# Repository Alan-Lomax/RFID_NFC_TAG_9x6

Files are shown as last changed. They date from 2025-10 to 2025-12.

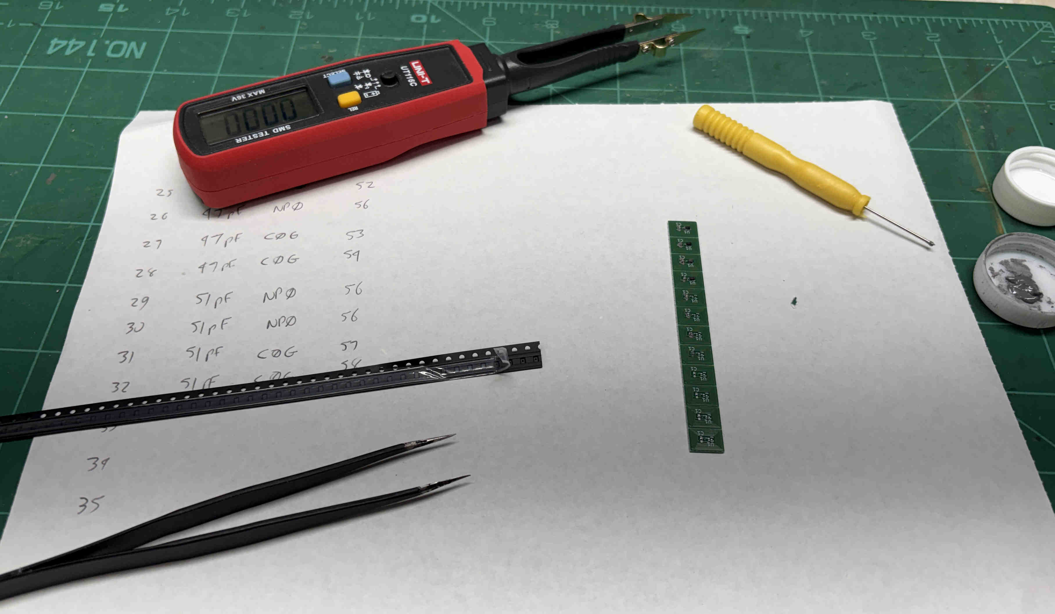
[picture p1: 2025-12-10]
Photos and testing/91 New Strip with varying C values.jpg

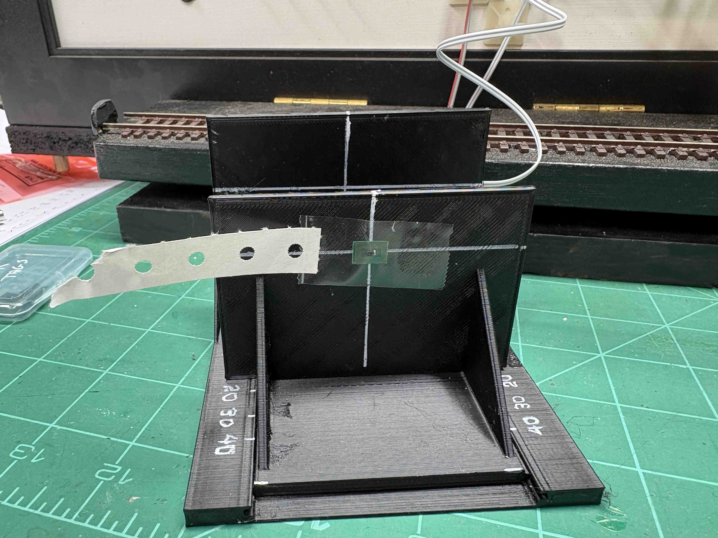
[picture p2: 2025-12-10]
Photos and testing/92 3D printed jig for range testing.jpg

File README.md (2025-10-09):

# RFID TAGs (PCB's and supporting documents)

## RFID_NFC_TAG_9x6
A simple small 9x6 mm PCB which uses two additional components to make up an RFID tag.
These are intended for use on model railways but applicable to other things.

## Description
Schematic KiCad files are included along with the GERBER files ready to send to a fab house for building.
It is recommended to have these panelized by the fab house into an array.
e.g.: 10 x 10 array for 100 tags per PCB). With the typical minimum order of 5 PCBs this will get you 500 tags.
Note that if the fab house can get the parts these PCB's could be ordered 'built' (With an associated cost of course)

For home assembly some experience with surface mount component assembly is recommended (hot plate method). 

## Technical
Designed for 13.56 MHz using the ISO15693 (vicinity Card) standard.
    Uses an NXP SL2S2602FTBX three pin IC (very small)
    And a 43pF capacitor for antanna matching ( 0402 SMD = very small )

## Other Equipment
For a complete RFID solution a tag also needs a suitable reader in order to energize the tag and get the information from it. 
For testing purposes I am using the StaRFIshRail hardware designed by the late Martin Snashell (no longer available)

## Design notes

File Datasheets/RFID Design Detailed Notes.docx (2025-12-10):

MERG RFID

General Architecture

Block Diagram Status | Data Concentrator RFID Reader Aerial Tag
| Data Concentrator | RFID Reader | Aerial | TAG
IFC | Purpose: Receive data from one or more readers and redistribute it in a commonly understood and well-defined format for use by established data consumers like JMRI | Purpose: Provide RF power and messaging to one or more aerials according to a well-defined industry standard protocol. Forward the received messages to the data concentrator along with an identifier as to what aerial was involved. | Purpose: Radiate the RFID energy in a detection field large enough for the model railway application but without excessive range that would result in spurious signals. | Purpose: Receive the RF energy power up and respond back to reader via the aerial (when in range) with at minimum the manufacturer assigned GUID. Do this fast enough for reliable reads as the tag passes over the aerial at a scale locomotive speed in excess of 100 MPH.
IFC | Left Side (IN) configuration data for MQTT HUB, CBUS address, events. Left Side (Out) MQTT+JSON and / or CBUS payloads Right Side: I2C messages to and from RFID Reader | Left Side (IN) I2C messages from Data Concentrator Left Side Out: I2C Payload data {Aerial #, GUID} Right Side: ISO/IEC 15693 RF messaging | In / Out: ISO/IEC 15693 RF messaging | In / Out: ISO/IEC 15693 RF messaging
IFC | TBD (Ras Pi PICO for example) | TBD (custom MERG board) | MOLEX 25mm x 15mm | Custom small PCB SL2S2602FTBX IC (https://www.nxp.com/products/SL2S2602) MLCC for Tuning
IFC | Investigating | Investigating | Lead lengths need to be matched with reader passives | Prototype designed and ordered. Parts on hand.

IFC = Issued for Comment

Designing My RFID Tag

As the design evolves regarding dimensions, number of turns, chip selection, then so dies the need for and value of a matching capacitor. Starting with the chip selection I wanted a currently Active product (not an obsolete or soon to be obsolete one). Using Application note AN11809 (https://www.nxp.com/docs/en/application-note/AN11809.pdf) (A product Comparison) I quickly settled on the SLIX 2 family and specifically the SL2S2602 family. (Must use that number to search for a data sheet, do not include the packaging suffix). A specific packaging of the chip is the SL2S2602FTBX which is the desired 3 pin SMD version.

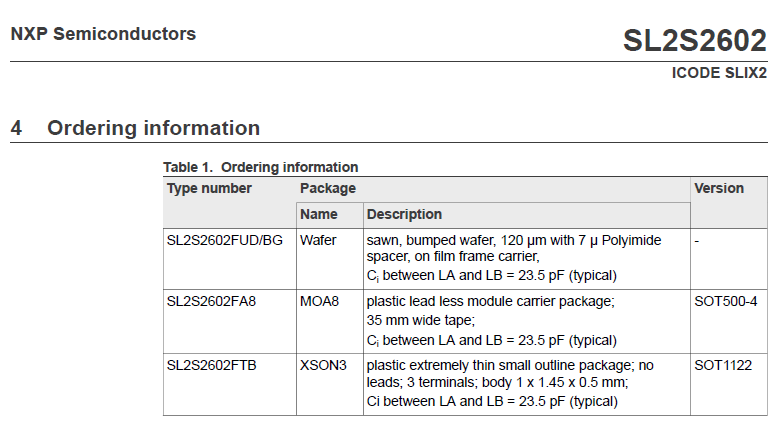
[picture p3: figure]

From the NXP website using the antenna calculator (link here (https://community.nxp.com/t5/NFC/bd-p/nfc?profile.language=en)) a matching capacitor of 42.2 pF is needed (nearest standard value is 43pF)

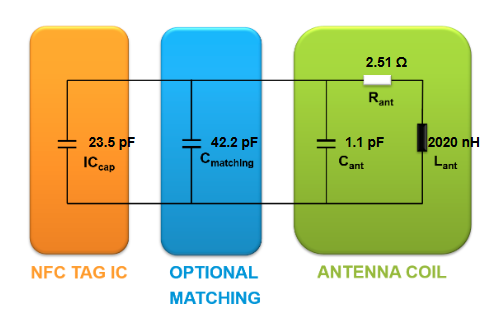
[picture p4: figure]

My specific design is below (created in KiCad Sept 15 2025). The tag below is 9mm x 6.5 mm on a 1mm thick FR4 PCB. There are 9 turns on each side (18 turns in total). The selected capacitor is in 0402 form (very small) and the chip is similarly tiny being in a XSON3 form factor. (see here (https://www.nxp.com/packages/SOT1122))

Both are of course surface mount.

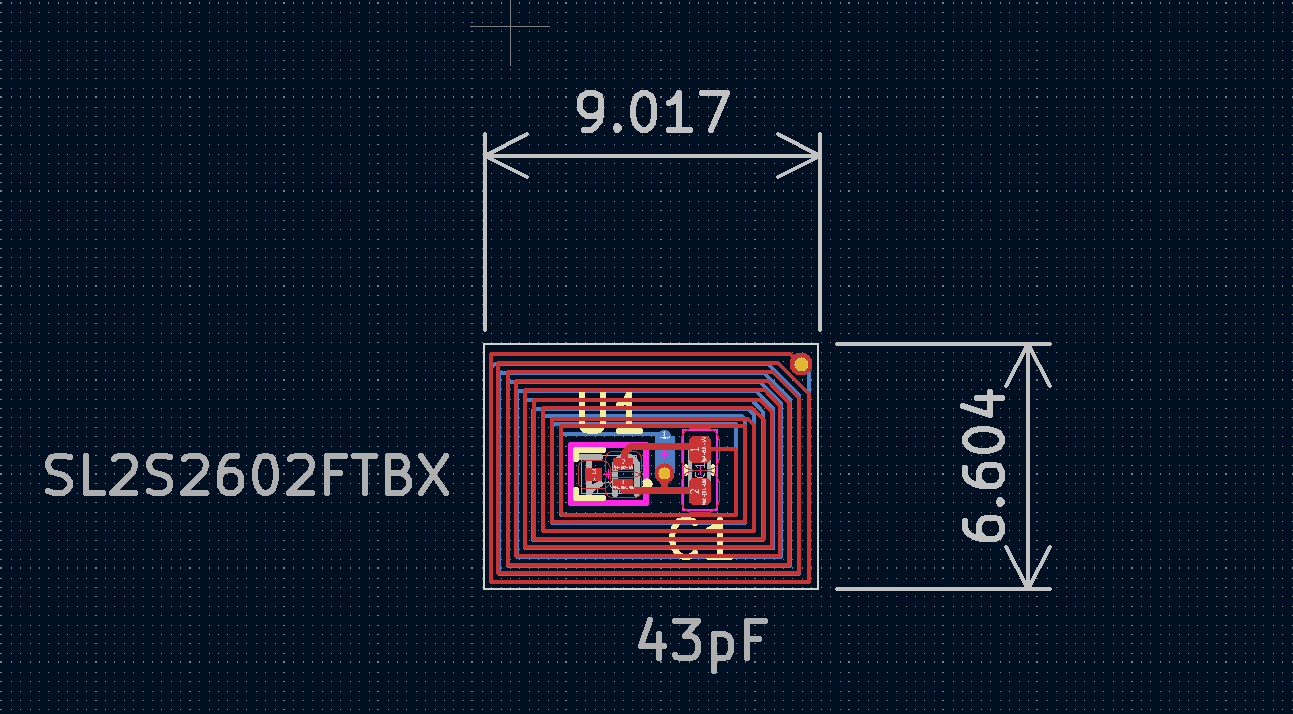
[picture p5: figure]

Above is the original PCB. Has since been tidied up a bit with slightly larger pads for NXP IC and more uniform aerial spacing. The Rev b has not been ordered (yet)

Purchase Details

Order number: Y46-4884191A

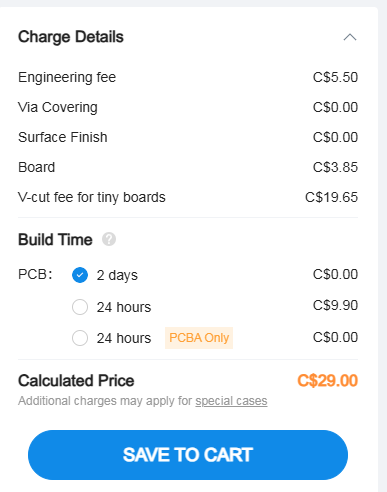
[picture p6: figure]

Note much higher V cut fee for tiny boards. In this case I am getting a 10 x 12 array.

(Limit for V-Cuts is 25 in each direction – so not close in that regard.)

Next is to source the components:

After Google Search … Mouser Canada.

## Order Number: 36928084 (https://www.mouser.ca/account/orders/detail)

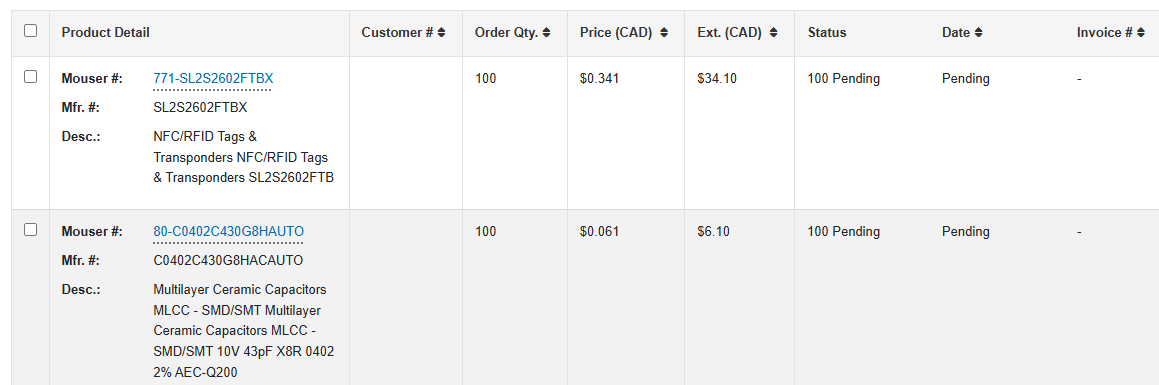
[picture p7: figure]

100 each of NXP chip and 0402 43pF Capacitor ($67 including $20 shipping) all in Canadian dollars.

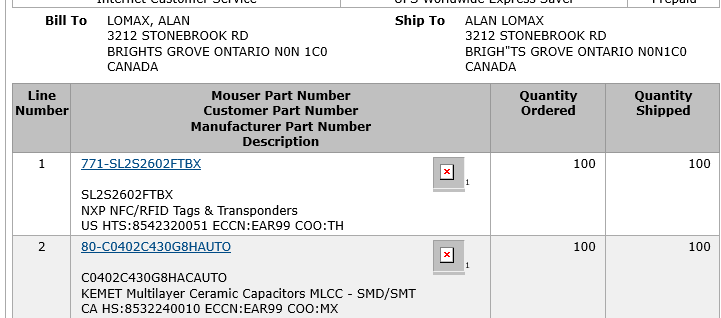
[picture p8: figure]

Mouser picked the parts and shipped them the same day.

On UNIT COST

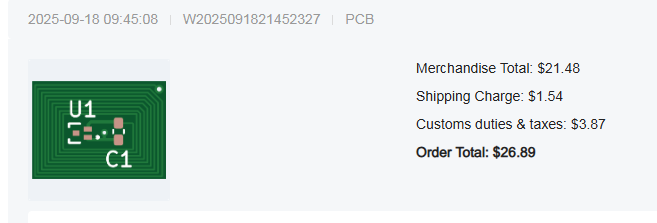
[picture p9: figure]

The PCB’s were about $30. Quite a bit higher than normal because there was a higher surcharge for “VeeCuts on Tiny boards”. Note – this is for Qty 5 PCBs that are 100mm x 100 mm. Each PCB has a 10x12 array of tags … so 600 tags for $30 works out to 5 cents for each Tag. The chips and capacitors were $68 Canadian for 100 of each (and $20 of that was for shipping.) so that is about $0.68 for those pieces. Per tag all in cost is 73 cents.

Pre-Assembled aka ‘Stuffed’ boards

It would be ideal to know what the ‘assembled cost’ would be from the likes of JLCPCB as for the tags specifically I think that would be preferred.

The process is described below:

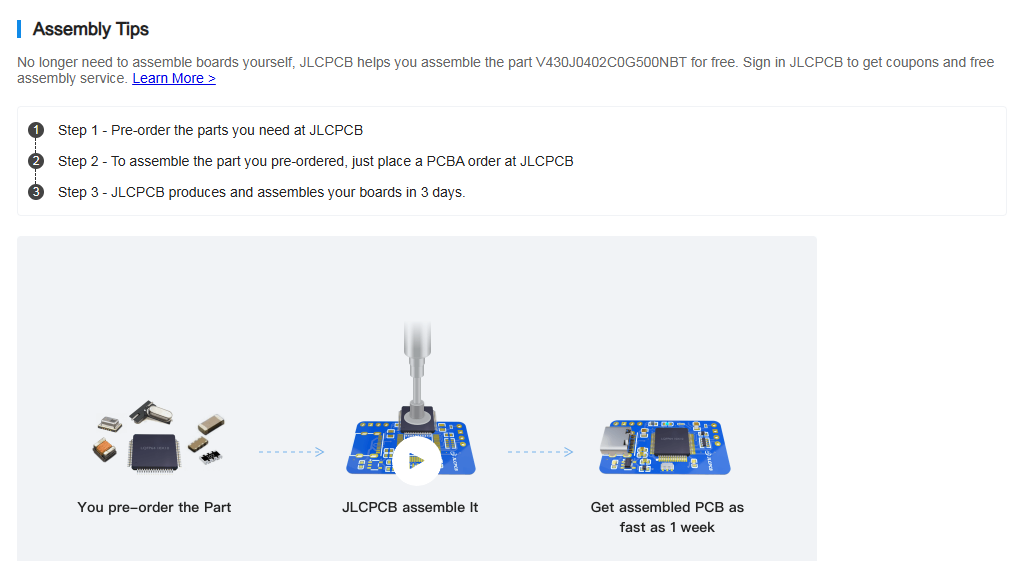
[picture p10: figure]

Investigating further: JLCPCB has in stock the capacitors (26k of them) and the NXP IC’s (Only 5 of them).

Preordering the IC’s triggered a minimum order size (but it was small at about 30 pieces) In qty 100 the ICs were about 55 cents each, the capacitors were under a penny each. What was not known is the engineering fee that might apply.

Commercial NXP Tags

(not explored yet)

Useful Network Analysis (Educational)

VSWR explained: https://www.youtube.com/watch?v=BijMGKbT0Wk

S parameters: https://www.youtube.com/watch?v=-Pi0UbErHTY

Smith Chart explained https://www.youtube.com/watch?v=rUDMo7hwihs

Common English “S term” translations

S21 – gain (Out is port 2, and in is Port 1)

S12 – noise blocking (Signal coming out of Port 1, from the port 2 side)

S11 – signal reflection (Power in on port 1 is also coming out on port 1)

S22 – signal reflection (ditto Port 2)

Build up and Testing of First Batch

Sep 30 2025

Prep

Solder paste was chosen with an indicated melt of 183 Deg C

A small dab was placed in the lid and mixed with a drop of IPA to make it smooth and creamy (was slightly grainy)

Used a solder aid tool to transfer miniscule dabs onto the solder pads.

For capacitor this was quite practical (larger pads).

For RFID chip the triad of pins were small and too close together and typically one blob covered all three.

With very fine tweezers parts were picked and verified for orientation (third pin is a tell tale) before placing on the paste.

Parts were only removed from packaging 4 at a time and only once placed were 4 more taken out of tape reel package.

The hot plate for pre heated to a pre soak temperature of 100 Deg C

Bake

The PCB with two complete rows was carefully put on the hot plate for a pre soak at 100 Deg C (5 minutes)

The temp was raised in stages with a short hold period at each (First hold was at 145 C, then 190 C and then finally temp was raised up to 205 C)

At 145 the IPA was obviously driven off – texture of solder paste changed.

At 190 some solder melt was occurring (but not the majority)

At 205C widespread melt was occurring in most places and this temperature was then held for 10 minutes.

It was noticed that one IC had popped up in the air 90 degrees to board. (In situ poking was attempted)

A close inspection then showed that capacitor on Tag 1 was MIA. A new one was retrieved from package and put in place
Cool Down | Hot plate was switched off and allowed to cool down. The PCB was removed from the hot plate (which was warm but not hot at this stage)
Prelim Testing | Using the StaRFIshRail test rig that I have I was able to test these tags for a simple go/no-go functionality test. Of the 24 tags only 4 failed. (Awesome result in my opinion)
Next Steps | Get my MQTT client up and running Scan the Working tags will be scanned for their UID Inspect and repair where possible the 4 failed tags.
Oct 1 2025
| Got my Raspberry Pi 4 up and running. It had a lot of updates to do. I reinstalled Eclipse mosquitto and it took a while to get it configured so that the HUB knew about the new IP address and that multiple clients were reading (subscribing) to it. Got there in the end.

# | Init P/F | Next Day GUID Read | GUID | Inspection Findings And Comments

1 | F | No response | No response | Misaligned IC. Touch with Solder Iron Retested. Failed (3x)
2 | P | | 09184854B8
3 | P | Failed to read | 09184854AA | Obvious paste. Touch C1 with Solder Iron Retested good
4 | P | | 09184854B0
5 | P | | 09184854BA
6 | P | | 09184854AD
7 | P | | 09184854B5
8 | P | | 09184854BB
9 | F | No response | No response | Misaligned IC. Touch with Solder Iron Retested. Failed (3x)
10 | P | | 09184854B1
11 | P | | 09184854BD
12 | P | | 09184854B2
13 | P | | 09184854A5
14 | P | | 09184854BC
15 | P | | 09184854AB
16 | P | | 09184854B7
17 | F | Failed to read | 09184854A9 | Misaligned Cap. Touch with Solder Iron Retested Good
18 | P | | 09184854AE
19 | P | | 09184854BE
20 | F | Failed to read | 09184854A7 | Misaligned Cap. Touch with Solder Iron Retested Good
21 | P | | 09184854B4
22 | P | | 09184854B9
23 | P | Failed to read | 09184854A2 | Nothing Obvious. Touch C1 with Solder Iron Retested good
24 | P | | 09184854AC

Below is board “as completed”

- Yellow squares indicate the initial failed positions.
- Orange squares failed the following day
- After rework only 1 and 9 remained inoperable (red dashed outline)

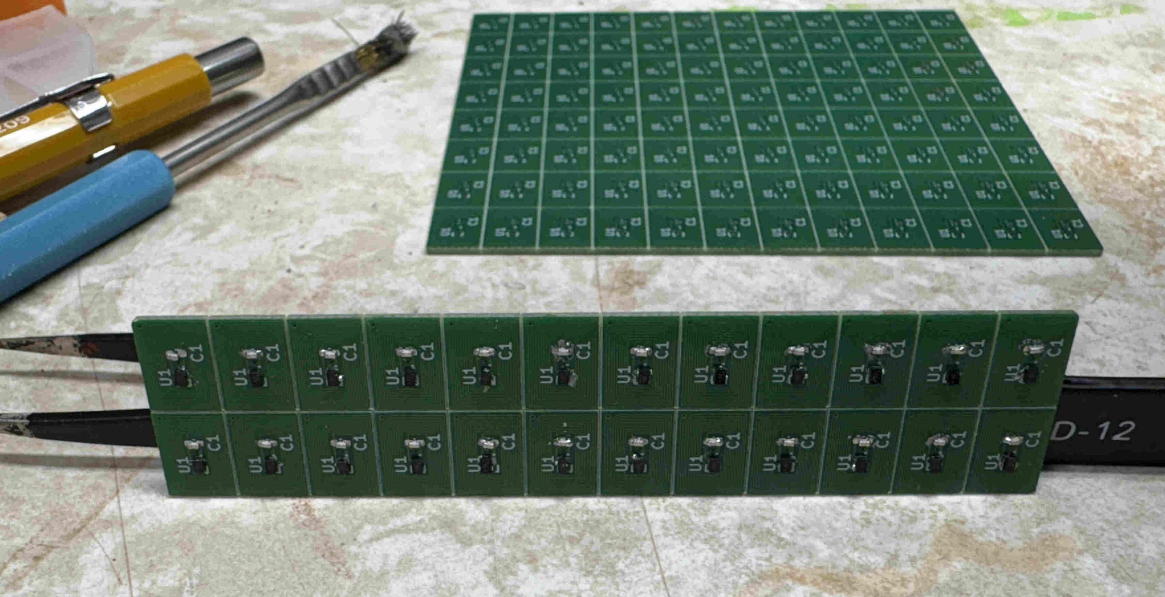
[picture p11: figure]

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
To: | David Harris 1545 York Place Victoria, BC Canada V8R 5X1
Tel | 250-216-0641
Item | Qty
PCB’s | 24
Capacitor C1 (43pF 50V MLCC) | 5
NFC RFID Chip SL2S2602FTBX | 5
Completed Boards | 5 | 6,12,14,15,24

David Harris

1545 York Place

Victoria, BC

Canada

V8R 5X1

To: | Nick Murphy 34 Droxford Crescent, Tadley, Basingstoke, Hampshire, England, RG26 3BA
Tel
Item | Qty
PCB’s | 24
Capacitor C1 (43pF 50V MLCC) | 5
NFC RFID Chip SL2S2602FTBX | 5
Completed Boards | 5 | 2,7,10,11,18

Mr. Nick Murphy

34 Droxford Crescent,

Tadley, Basingstoke,

Hampshire, England,

RG26 3BA

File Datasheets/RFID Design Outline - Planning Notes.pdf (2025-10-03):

MERG RFID

General Architecture

Block Diagram Status | Data RFID Reader Aerial Tag Concentrator
| Data Concentrator | RFID Reader | Aerial | TAG
IFC | Purpose: Receive data from one or more readers and redistribute it in a commonly understood and well-defined format for use by established data consumers like JMRI | Purpose: Provide RF power and messaging to one or more aerials according to a well-defined industry standard protocol. Forward the received messages to the data concentrator along with an iden!fier as to what aerial was involved. | Purpose: Radiate the RFID energy in a detec!on field large enough for the model railway applica!on but without excessive range that would result in spurious signals. | Purpose: Receive the RF energy power up and respond back to reader via the aerial (when in range) with at minimum the manufacturer assigned GUID. Do this fast enough for reliable reads as the tag passes over the aerial at a scale locomo!ve speed in excess of 100 MPH.
IFC | Le" Side (IN) configura!on data for MQTT HUB, CBUS address, events. Le" Side (Out) MQTT+JSON and / or CBUS payloads Right Side: I2C messages to and from RFID Reader | Le" Side (IN) I2C messages from Data Concentrator Le" Side Out: I2C Payload data {Aerial #, GUID} Right Side: ISO/IEC 15693 RF messaging | In / Out: ISO/IEC 15693 RF messaging | In / Out: ISO/IEC 15693 RF messaging
IFC | TBD (Ras Pi PICO for example) | TBD (custom MERG board) | MOLEX 25mm x 15mm | Custom small PCB SL2S2602FTBX IC MLCC for Tuning
IFC | Inves*ga*ng | Inves*ga*ng | Lead lengths need to be matched with reader passives | Prototype designed and ordered. Parts on hand.

IFC = Issued for Comment

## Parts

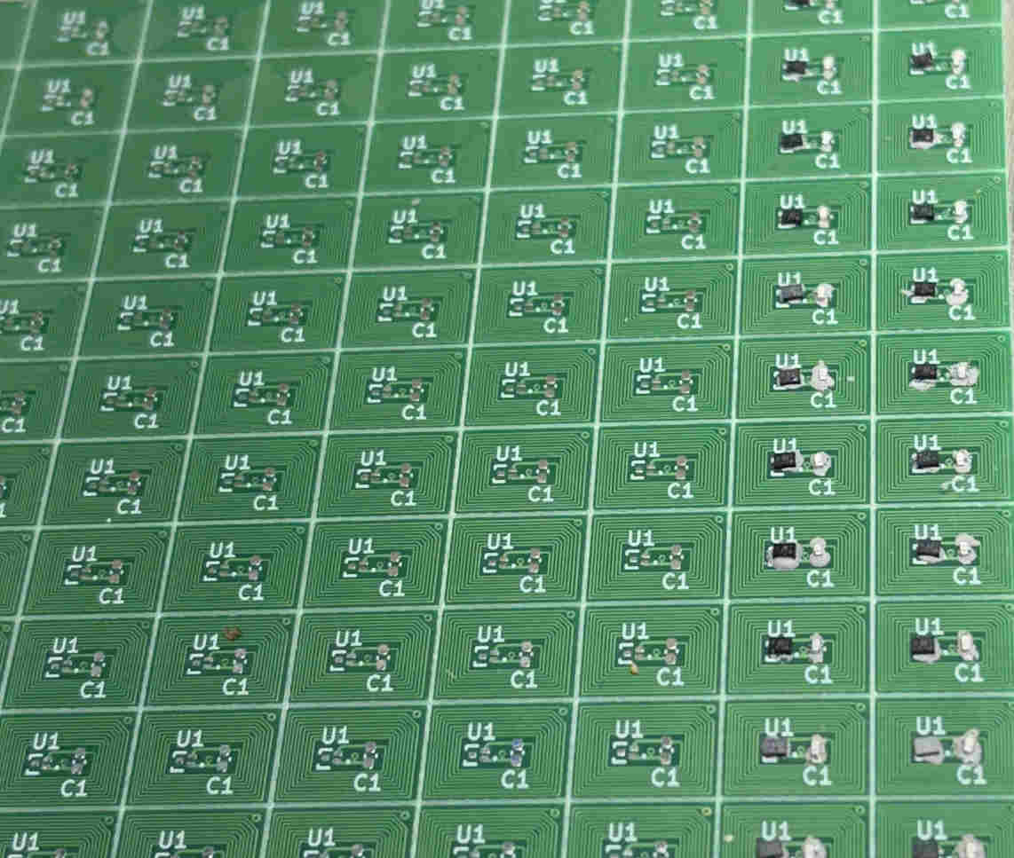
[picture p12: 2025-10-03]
Photos and testing/01 Close up view on the Hot plate after dabbing solder paste and placing parts into the paste IMG_8041.JPG

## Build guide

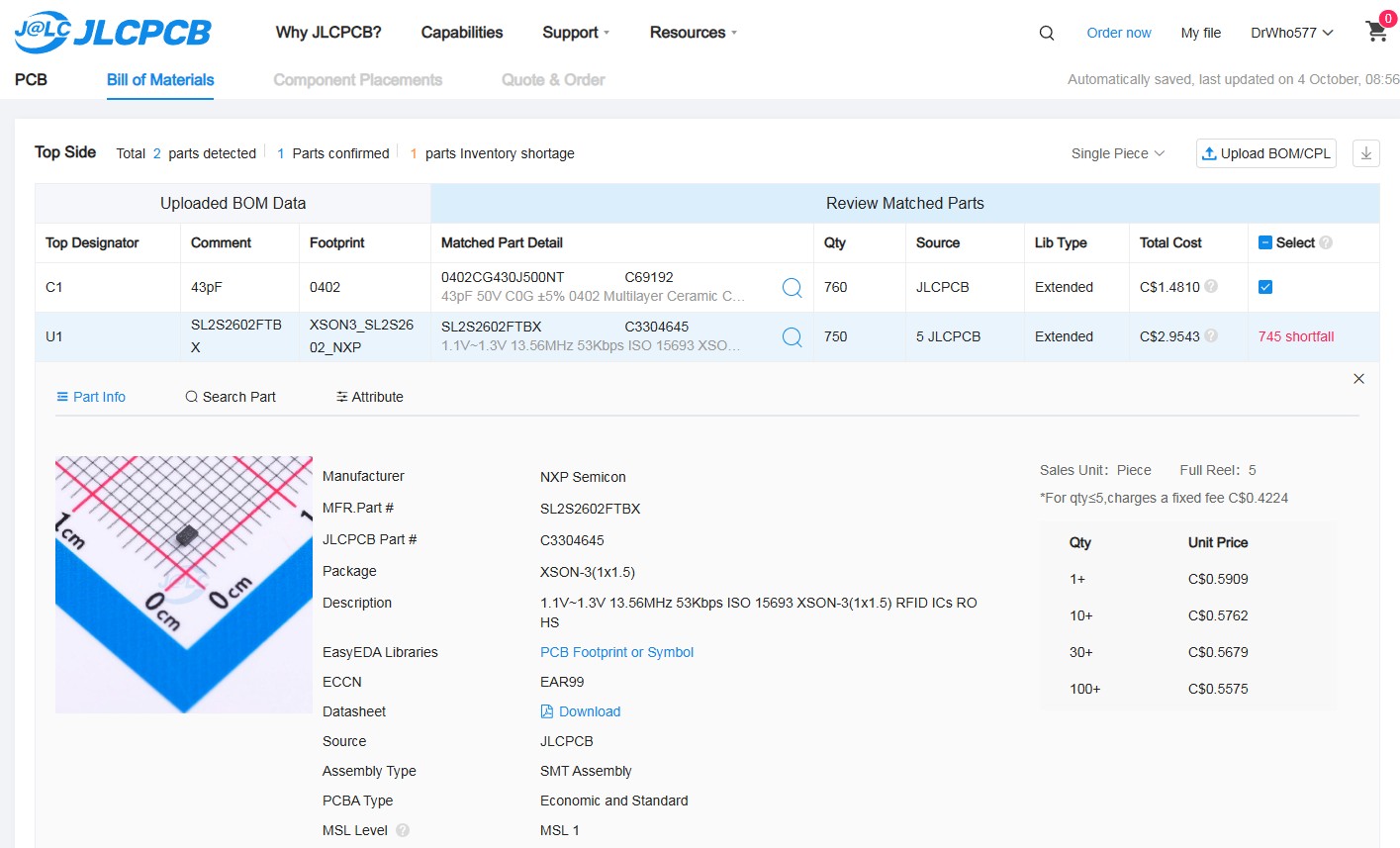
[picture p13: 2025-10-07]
Invoices/10 Exploring JLCPCB assembly Screenshot 2025-10-04 091636.jpg

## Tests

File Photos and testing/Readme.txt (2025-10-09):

PCB's arrived and were unboxed.

Solder paste was chosen with a indicated melt of 183 Deg C
A small dab was placed in the lid and mixed with a drop of IPA to make it smooth and creamy (was slightly grainy)
Used a solder aid tool to transfer miniscule dabs onto the solder pads. 
   For capacitor this was practical. 
   For RFID chip the triad of pins were too close together and typically one blob covered all three.
With very fine tweezers parts were placed on the paste. Each chip was verified for orientation (third pin is a tell tale)
Parts were only removed from packaging 4 at a time and only once placed were 4 more taken out of tape package.
The PCB with two complete rows was carefully put on the hot plate for a pre soak at 100 Deg C (5 minutes) This to drive off the IPA solvent.
Temp was raised in stages with a short hold period at each (145 C, 190 C and then finally up to 205 C)
At 145 the IPA was obviously driven off, at 190 some melt was occuring (but not the majority)
At 205C melt was occuring in most places and this temperature was held for 10 minutes. In hindsight should have gone a little higher (210)
It was noticed that one IC had popped up in the air 90 degrees to board. (Surface tension)
A close inspection then showed that capacitor on Tag 1 was MIA. 
A new one was retrieved from package and put in place. I Suspect during IPA boiloff it popped somewhere.

Hot plate was switched off and allowed to cool down. 

The PCB was removed from the hot plate (which was warm but not hot at this stage)
Tags were numbered with a paint marker for tracking purposes.

Using the Starfishrail test rig that I have I was able to test these tags for a simple go/no-go functionality test.
Of the 24 tags only 4 had failed.  (Awesome result in my opinion)

The 4 failed tags were later inspected for issues and of these two were recovered by simply remelting the solder around the Capacitor.

All working tags wiere ssanned for their UID whjich was recorded. Also reading at distance was verified.

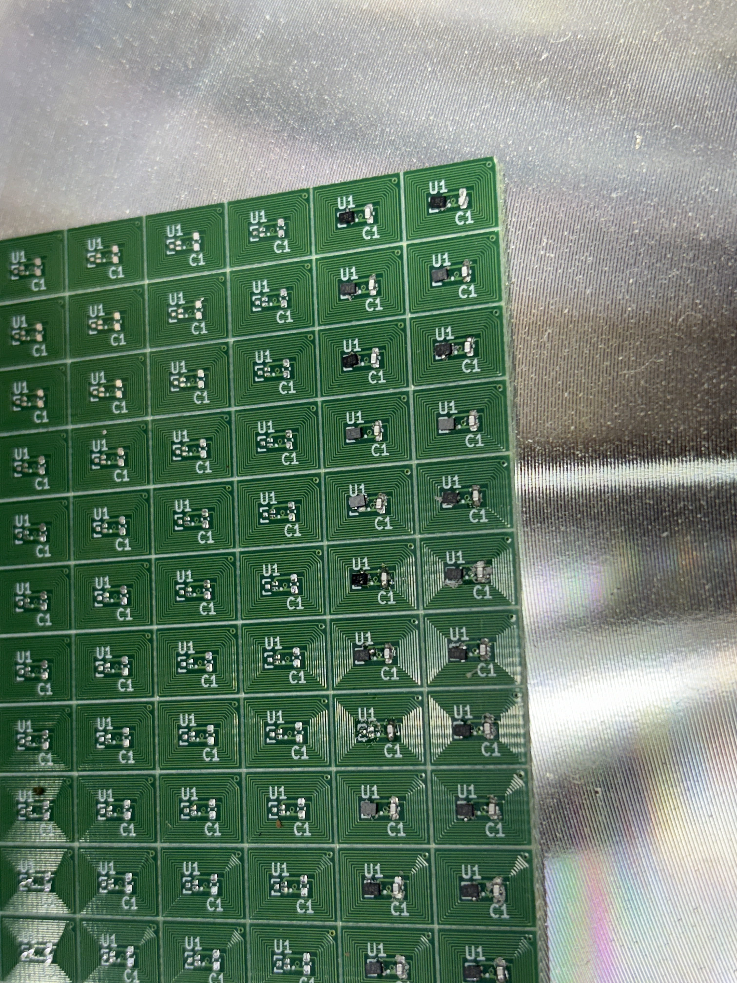
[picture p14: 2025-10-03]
Photos and testing/04 Capacitor on Tag 1 looks skewed - maybe shorting IMG_8044.JPG

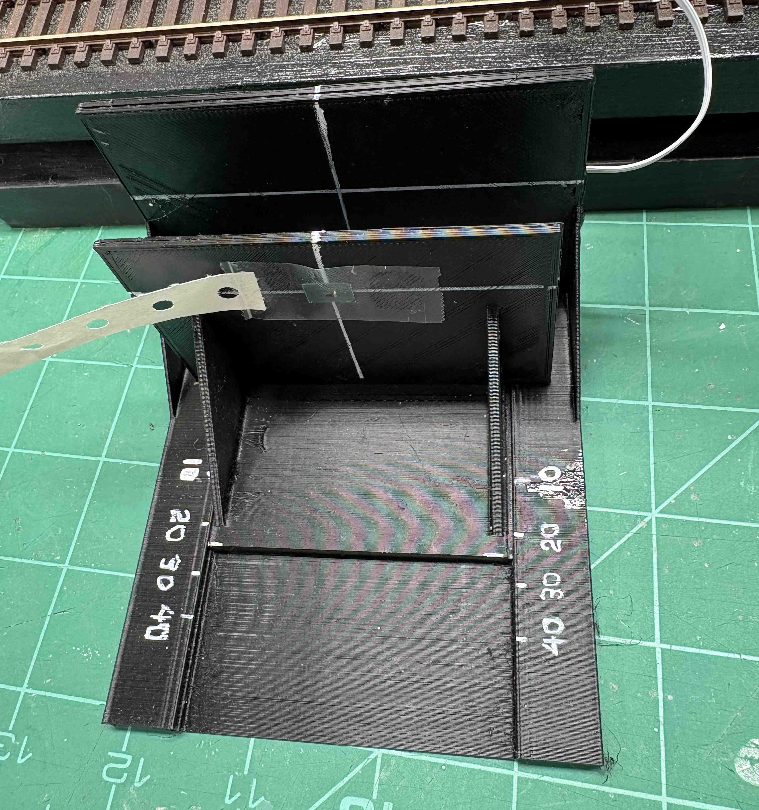
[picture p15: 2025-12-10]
Photos and testing/92 Tag on near side of sliding platform with aerial on far side of fixed platform (paint lines for alignment).jpg

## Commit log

2025-10-03 Initial Commit After First Trial build
    13.56 MHz RFID Tag (size 6x9mm) using NXP SLIX2 RFID tag IC and ISO15693 standard.
    [RFID_NFC_TAG_9x6-B_Cu.gbr, RFID_NFC_TAG_9x6-B_Mask.gbr, RFID_NFC_TAG_9x6-B_Paste.gbr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]
2025-10-03 Tidy up of trace spacing. Added larger pads to NFC chip.
    Initial design had irregular spacing between traces on top and bottom layer. With this revision the lower copper was used for the spacing on the top layer, and vice versa. In this way a very even track spacing was achieved which cut down on overall size of PCB fractionally.
    From the first batch initial success was achieved on 20 of 24 tags. Of the remaining 4 2 were fixed by touching solder to the caps.
    The remaining issues were with the NXP chip where I could not get heat to bottom for reheat soldering. Slightly larger pads were added wxtending out from under the IC outline which will also allow accepting a little more solder paste.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
    [RFID_NFC_TAG_9x6-B_Cu.gbr, RFID_NFC_TAG_9x6-B_Mask.gbr, RFID_NFC_TAG_9x6-B_Paste.gbr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]
2025-10-07 Tidy up tracks and pads
    [bom.csv, designators.csv, positions.csv]
2025-10-09 File Clean Up
    Put KiCad files in own folder
    Remove backup ZIP files
    Update Readme text files
    [RFID_NFC_TAG_9x6-B_Cu.gbr, RFID_NFC_TAG_9x6-B_Mask.gbr, RFID_NFC_TAG_9x6-B_Paste.gbr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]
2025-10-09 Create .gitignore
    Based on the KiCad .gitignore template
2025-12-10 Tag Updates After Testing
    [RFID_NFC_TAG_9x6.kicad_pcb, RFID_NFC_TAG_9x6.kicad_sch]
